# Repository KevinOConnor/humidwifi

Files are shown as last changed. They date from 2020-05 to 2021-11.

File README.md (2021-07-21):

This is an experimental pcb design for a battery powered wireless
humidity, temperature, and pressure sensor. It uses an esp32 wifi chip
along with a bme280 sensor.

This is an experiment. There is no support for this project.

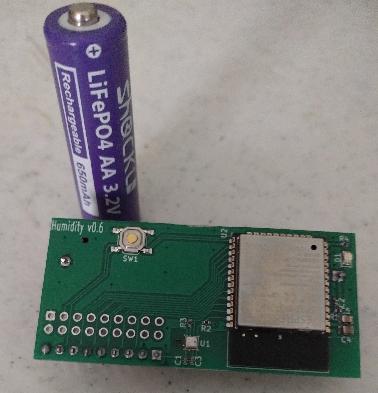
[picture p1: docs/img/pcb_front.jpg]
pcb_front


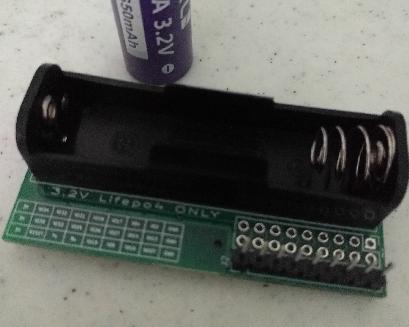
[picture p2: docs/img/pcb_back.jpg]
pcb_back


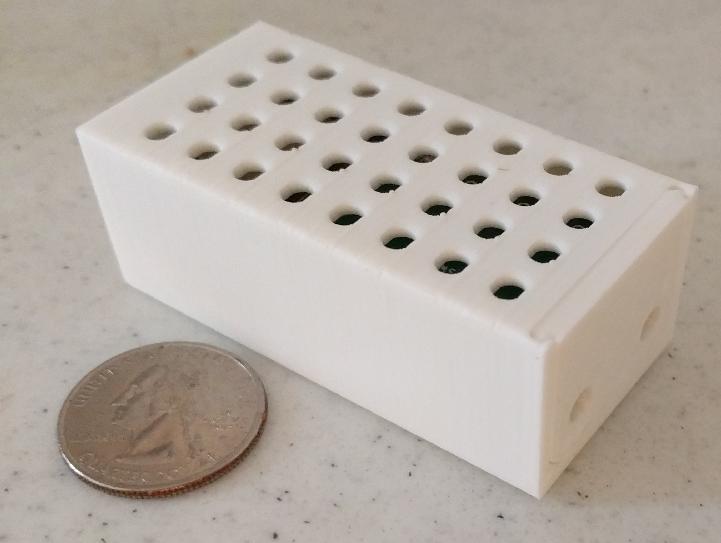
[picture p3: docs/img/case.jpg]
case


There is some information on the pcb design in the
[pcb document](docs/PCB.md).

There is some information on building the firmware in the
[firmware document](docs/Firmware.md).

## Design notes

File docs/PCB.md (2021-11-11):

The PCB design files can be found in the [pcb/](../pcb/) directory.
The boards were designed using [KiCad](https://kicad.org/) and
manufactured using [JLC PCB](https://jlcpcb.com/).

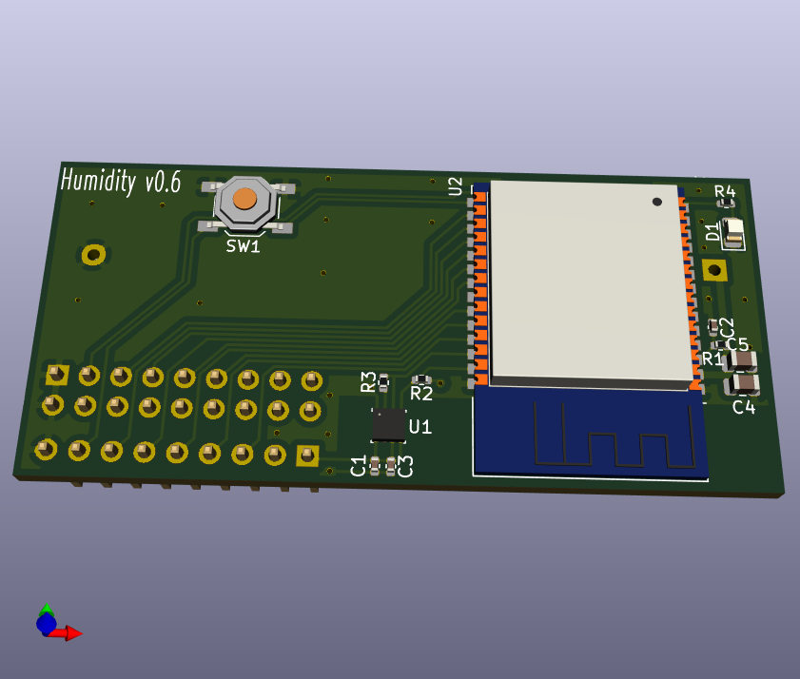
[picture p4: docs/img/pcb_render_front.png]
pcb_render_front


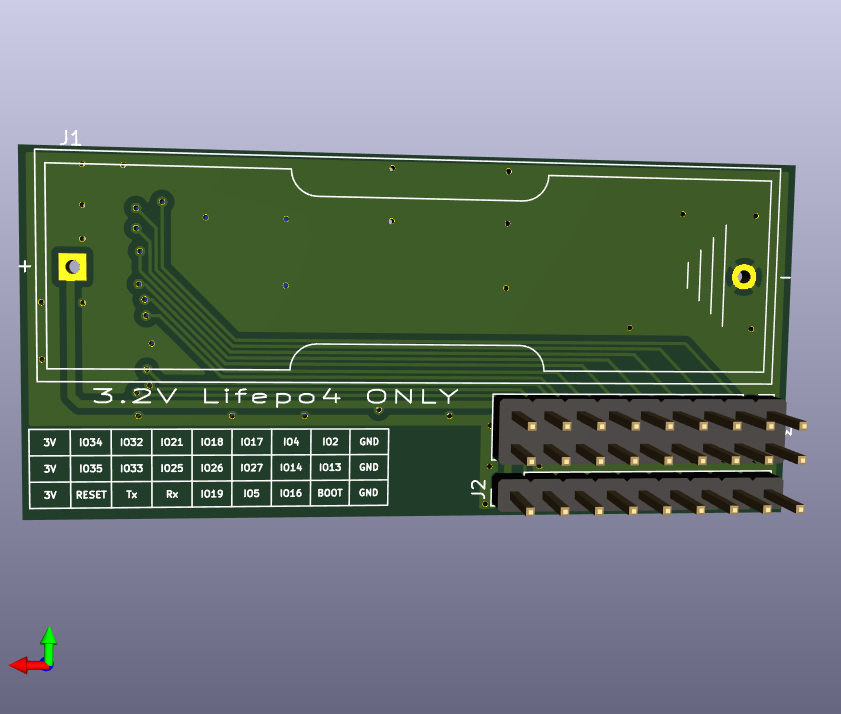
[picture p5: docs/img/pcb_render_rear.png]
pcb_render_rear


The board is designed to use a 3.2V LiFePO4 battery. The device will
not function properly with a 3.7V Lithium battery nor with a regular
alkaline AA battery - inserting an incorrect battery is likely to
permanently damage the board and it may result in a fire hazard.

Case
====

The design for a plastic case can be found in the [case/](../case/)
directory. It can be printed using a 3d-printer. The case was designed
using [OpenSCAD](https://www.openscad.org/).

case

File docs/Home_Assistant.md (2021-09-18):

To use these devices with Home Assistant, the easiest way is to seed Home Assistant manually
with MQTT Discovery commands about the device and the state topic.

To do this, run the `scripts/home_assistant_config.py` script, and provide the name of
the device.  This will print out the commands to run with `mosquitto_pub` to seed Home Assistant.

Once Home Assistant is seeded with the configuration, it typically does not need it again.  It will
pull the data from the `/data` topic as instructed moving forward.

Example
=======

```
python3 ./scripts/home_assistant_config.py --name humidwifi-living-room --host mqtt.local

> run:
> mosquitto_pub -t 'homeassistant/sensor/humidwifi-living-room/temp/config' -h mqtt.local -m '{"name": "Temperature", "device_class": "temperature", "unique_id": "humidwifi-living-room-name", "state_topic": "humidwifi-living-room/data", "unit_of_measurement": "\u00b0C", "value_template": "{{value_json.temperature}}", "device": {"manufacturer": "espressif", "identifiers": "humidwifi-living-room", "name": "humidwifi-living-room"}}' -r
> mosquitto_pub -t 'homeassistant/sensor/humidwifi-living-room/humidity/config' -h mqtt.local -m '{"name": "Humidity", "device_class": "humidity", "unique_id": "humidwifi-living-room-humidity", "state_topic": "humidwifi-living-room/data", "unit_of_measurement": "%", "value_template": "{{value_json.humidity}}", "device": {"manufacturer": "espressif", "identifiers": "humidwifi-living-room", "name": "humidwifi-living-room"}}' -r
> mosquitto_pub -t 'homeassistant/sensor/humidwifi-living-room/pressure/config' -h mqtt.local -m '{"name": "Pressure", "device_class": "pressure", "unique_id": "humidwifi-living-room-pressure", "state_topic": "humidwifi-living-room/data", "unit_of_measurement": "hPa", "value_template": "{{value_json.pressure}}", "device": {"manufacturer": "espressif", "identifiers": "humidwifi-living-room", "name": "humidwifi-living-room"}}' -r
> mosquitto_pub -t 'homeassistant/sensor/humidwifi-living-room/voltage/config' -h mqtt.local -m '{"name": "Voltage", "device_class": "voltage", "unique_id": "humidwifi-living-room-voltage", "state_topic": "humidwifi-living-room/data", "unit_of_measurement": "V", "value_template": "{{value_json.battery}}", "device": {"manufacturer": "espressif", "identifiers": "humidwifi-living-room", "name": "humidwifi-living-room"}}' -r

````

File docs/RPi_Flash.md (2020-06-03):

This document provides some hints on flashing the esp32 chip using a
Raspberry Pi's GPIO pins.

Wiring
======

The PCB's GPIO pins (from esp32 chip to board edge) are:
`GND, Tx, Rx, Boot, Reset, 3.3V`

Start by removing the battery and then use female to female jumper
cables to connect the PCB pins to the Raspberry Pi's GPIO
pins. Connect ground first and connect 3.3V last.

Important! Do not connect the 3.3V line while the battery is
installed.

Make these connections:
```
GND   -> RPi GND  (Pin 6)
Tx    -> RPi Rx   (Pin 10)
Rx    -> RPi Tx   (Pin 8)
Boot  -> RPi GND  (Pin 14)
Reset -> Not connected
3.3V  -> RPi 3.3V (Pin 1)
```

See https://pinout.xyz/ for a picture showing the Raspberry Pi GPIO
pins.

Software
========

The easiest way to build and install the software is to install and
compile the full
[esp-idf](https://docs.espressif.com/projects/esp-idf/en/v4.1-beta1/get-started/index.html)
environment on the Raspberry Pi and run `idf.py menuconfig ; idf.py
build ; idf.py -p /dev/ttyAMA0 flash`.

As an alternative, it is also possible to install just the idf
flashing tool and copy the binary components from a build on a desktop
computer. To do this, first install the esp32 flash tool:
```
virtualenv ~/esphome-env
~/esptool-env/bin/pip install esptool
```

Then copy the firmware files from a desktop to the Raspberry Pi with
something like:
```
cd /path/to/humidwifi/
rsync -av fw/build/partition_table/partition-table.bin fw/build/bootloader/bootloader.bin fw/build/humidwifi.bin pi@raspberrypi:~/
```

If one wishes to first erase the flash (which is not normally needed)
then one can run the following on the Raspberry Pi:
```
~/esptool-env/bin/esptool.py -p /dev/ttyAMA0 erase_flash
```
After this completes (it will take 30 seconds or so to erase the
chip), reset the PCB by carefully unplugging the 3.3V pin from the
PCB, wait 5 seconds, and then reconnect the 3.3V wire.

One can program the new flash with:
```
~/esptool-env/bin/esptool.py -p /dev/ttyAMA0 write_flash 0x8000 partition-table.bin 0x1000 bootloader.bin 0x10000 humidwifi.bin
```

Once the new firmware is written, carefully unplug the 3.3V wire
followed by the remaining wires. Insert the battery to start the new
firmware.

Important! Do not install the battery while the the 3.3V line is
connected.

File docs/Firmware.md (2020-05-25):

There is custom firmware available for this PCB design in the
[fw/](../fw/) directory. This document provides some overview
information for the firmware.

Building the firmware
=====================

The code uses the
[esp-idf](https://docs.espressif.com/projects/esp-idf/en/latest/esp32/index.html)
framework. To build the firmware run:

```
cd /path/to/humidwifi/
docker run --rm -v ./fw:/project -w /project -it espressif/idf:release-v4.1 idf.py menuconfig
docker run --rm -v ./fw:/project -w /project -it espressif/idf:release-v4.1 idf.py build
```

In the menuconfig step, be sure to enter the `Application settings for
'humidity wifi' project` and configure the appropriate MQTT and
network settings.

After configuring and building the software it will be necessary to
flash the software to the board. This can be done by running something
like `docker run --rm -v ./fw:/project -w /project -it
espressif/idf:release-v4.1 idf.py flash`, but it will require
configuring docker to have direct access to the device's serial port
(which is outside the scope of this document).

Overview and notes
==================

The software was designed to minimize battery usage during normal
operation. The goal is to keep the esp32 in "deep sleep" mode for the
vast majority of its lifetime. Sensor readings are taken periodically,
the results are stored to the esp32's "low power rtc memory", and then
the device reenters deep sleep mode. Periodically the device will also
turn on the radio, upload stored sensor readings, check for an
"over-the-air flash request", and then turn off the radio. Priority is
given to minimizing the amount of time that the wifi radio is enabled.
Minimizing the radio time greatly reduces the battery drain.

The software performs all uploads via an MQTT server. It should be
possible to configure the MQTT URI to use a username/password and/or
to use a TLS encrypted connection. The code does not currently have a
method to store TLS certificates however. The code does set the MQTT
"retain" flag, which may not be compatible with some "cloud" MQTT
servers. It should work with a local
[Mosquitto MQTT](https://mosquitto.org/) server.

Battery measurement
===================

The firmware uses an esp32 "trick" to measure the battery voltage. It
enables both the pullup and pulldown resistors of an unconnected ADC2
pin and then performs an ADC measurement. The pullup/pulldown
resistors form a "voltage divisor" which can be used to measure the
battery voltage. In theory, this "trick" would result in an ADC
reading that is half the battery voltage and therefore one would scale
this value by a factor of 2.0 to obtain the actual battery voltage.
However, the on-chip pullup/pulldown resistors may have slightly
different resistances.

The resistance difference is usually minor, but one can account for it
if they wish. While the device is powered and running, use a
multimeter to measure the actual voltage across the battery terminals.
Compare this voltage with the voltage reported by the software and
update the `Voltage scale` parameter in the "menuconfig" tool
accordingly.

Over-the-air flash
==================

It is possible to flash new versions of the software using an "over
the air" update. This is done by writing a URL to the `topic/ota_url`
MQTT topic (where `topic` is the topic prefix specified in
menuconfig). The URL should be an http (or https) link. For example:

```
mosquitto_pub -t "topic/ota_url" -m "http://myserver:8080/humidwifi.bin" -r
```

When the device next attempts to upload values, it will look for that
topic and then attempt to download the given firmware. One can launch
a temporary http server with something like:

```
cd /path/to/humidwifi/fw/build/
python -m SimpleHTTPServer 8080
```

It should be possible to use an https server, however the code does
not currently verify TLS certificates.

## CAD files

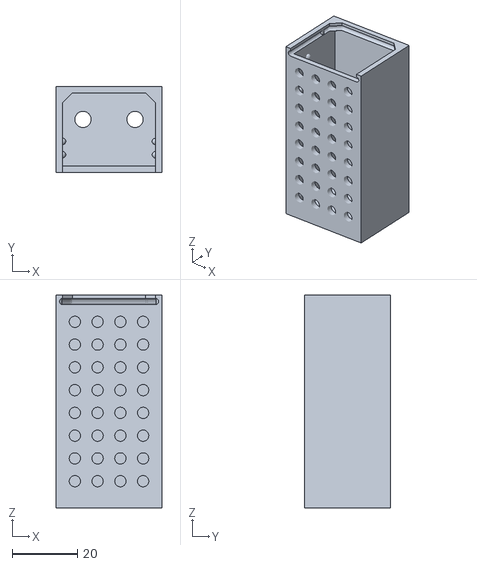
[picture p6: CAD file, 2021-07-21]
case/humcase.stl
32.5 x 26.5 x 65.5

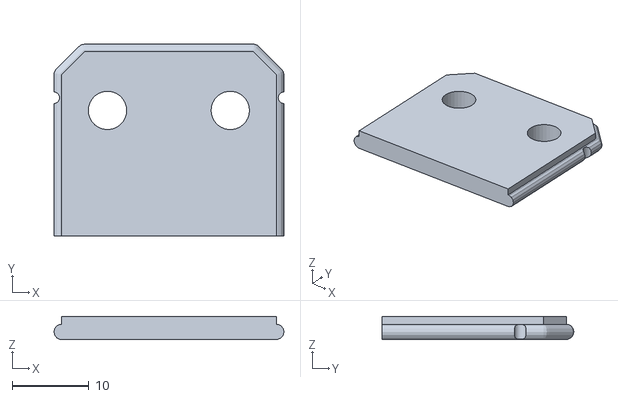
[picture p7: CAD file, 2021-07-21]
case/humlid.stl
30.0 x 25.0 x 3.00

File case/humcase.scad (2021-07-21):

// Case for storing humidity sensor
//
// Copyright (C) 2020-2021  Kevin O'Connor <kevin@koconnor.net>
//
// This file may be distributed under the terms of the GNU GPLv3 license.

// Generate STL using OpenSCAD:
//   openscad humcase.scad -o humcase.stl

pcb_width = 28;
pcb_thick = 1.6;
pcb_length = 60;
batt_thick = 18.5;
esp_thick = 3.5;
extra_thick = 0;
wall_width = 2;
guide_diamenter = 2;
lid_height = 3;
lid_diameter = 2;
air_hole_diameter = 3.5;
slack = 0.5;
CUT = 0.01;
$fs = 0.5;

module lid_frame(width, thick) {
    taper = 3;
    module raw_lid() {
        module rpoint(x1, y1) {
            translate([x1, y1, lid_diameter/2])
                sphere(d=lid_diameter);
        }
        hull() {
            rpoint(0, 0);
            rpoint(0, thick-taper);
            rpoint(taper, thick);
            rpoint(width-taper, thick);
            rpoint(width, thick-taper);
            rpoint(width, 0);
        }
        linear_extrude(height=lid_height) {
            polygon([[0,0], [0, thick-taper], [taper, thick],
                     [width-taper, thick], [width, thick-taper], [width, 0]]);
        }
    }
    module dimples() {
        dimple_diameter = 1.5;
        x_offset = lid_diameter/2;
        y_pos = thick - taper - 3;
        translate([-x_offset, y_pos, -CUT])
            cylinder(h=lid_height + 2*CUT, d=dimple_diameter, $fs=.1);
        translate([width + x_offset, y_pos, -CUT])
            cylinder(h=lid_height + 2*CUT, d=dimple_diameter, $fs=.1);
    }
    difference() {
        raw_lid();
        translate([-lid_diameter/2 - CUT, -lid_diameter, 0])
            cube([width + lid_diameter + 2*CUT, lid_diameter,
                  lid_height + 2*CUT]);
        dimples();
    }
}

module battery_air_hole(x, y) {
    batt_air_hole_diameter = 5;
    translate([x, y, -CUT])
        cylinder(h=lid_height + 2*CUT, d=batt_air_hole_diameter);
}

batt_hole_y = extra_thick + esp_thick + pcb_thick + wall_width + batt_thick/2;

module lid() {
    difference() {
        lid_frame(pcb_width, batt_thick + esp_thick + extra_thick + wall_width);
        battery_air_hole(6, batt_hole_y);
        battery_air_hole(pcb_width-6, batt_hole_y);
    }
}

module case() {
    width = pcb_width + slack;
    thick = batt_thick + esp_thick + extra_thick + slack;
    height = pcb_length + lid_height + slack;
    two_wall = 2 * wall_width;
    module box() {
        difference() {
            cube([width + two_wall, thick + two_wall, height + wall_width]);
            translate([wall_width, wall_width, wall_width])
                cube([width, thick, height - lid_height + 2*CUT]);
            translate([wall_width, -CUT, wall_width + pcb_length + slack + CUT])
                lid_frame(width, thick + wall_width);
        }
    }
    module pcb_guide(z) {
        top_space = esp_thick + wall_width + extra_thick;
        guide_space = pcb_thick + guide_diamenter + slack;
        front_place = wall_width;
        rear_place = wall_width + width;
        translate([front_place, top_space, z+wall_width])
            sphere(d=guide_diamenter);
        translate([front_place, top_space + guide_space, z+wall_width])
            sphere(d=guide_diamenter);
        translate([rear_place, top_space, z+wall_width])
            sphere(d=guide_diamenter);
        translate([rear_place, top_space + guide_space, z+wall_width])
            sphere(d=guide_diamenter);
    }
    module main_box() {
        box();
        pcb_guide(4);
        pcb_guide(15);
        pcb_guide(pcb_length-15);
        pcb_guide(pcb_length-4);
    }
    module air_holes(xpos_list, zpos_list) {
        module air_hole(x, z) {
            translate([x, -CUT, z])
                rotate([-90, 0, 0])
                    cylinder(h=wall_width + 2*CUT, d=air_hole_diameter);
        }
        center_x = (width + two_wall) / 2;
        center_z = (height + wall_width) / 2;
        gap = 2 * air_hole_diameter;
        for (xpos=xpos_list) {
            x = center_x + gap * xpos;
            for (zpos=zpos_list) {
                z = center_z + gap * zpos;
                air_hole(x, z);
            }
        }
    }
    difference() {
        main_box();
        air_xlist = [-1.5, -0.5, .5, 1.5];
        air_zlist = [-3.5, -2.5, -1.5, -0.5, .5, 1.5, 2.5, 3.5];
        air_holes(air_xlist, air_zlist);
        battery_air_hole(wall_width + slack / 2 + 6, batt_hole_y);
        battery_air_hole(width + wall_width - slack / 2 - 6, batt_hole_y);
    }
}

//
// Object selection
//

case();
//lid();

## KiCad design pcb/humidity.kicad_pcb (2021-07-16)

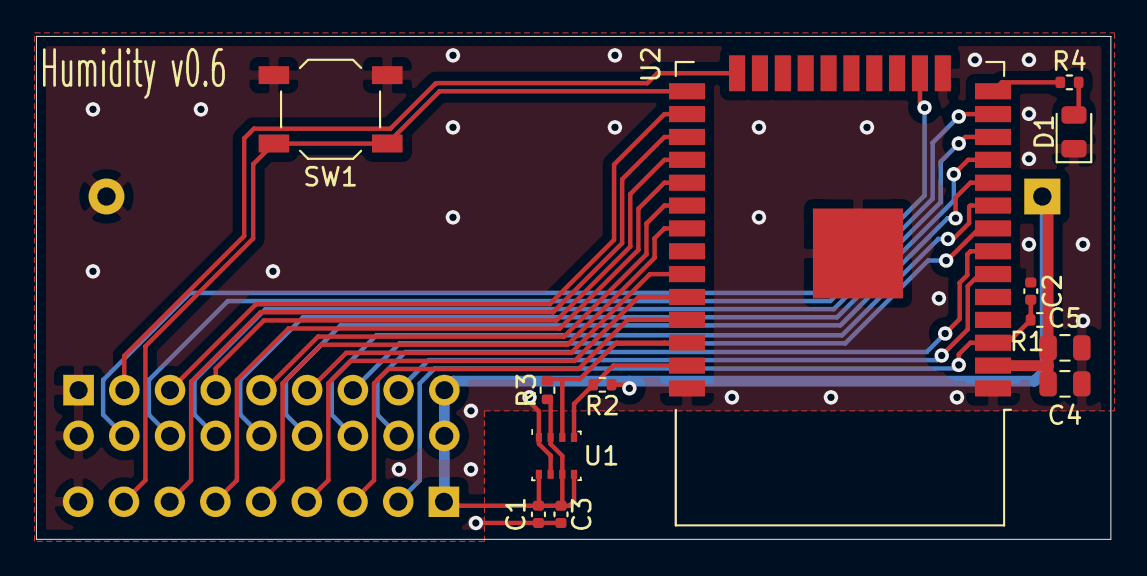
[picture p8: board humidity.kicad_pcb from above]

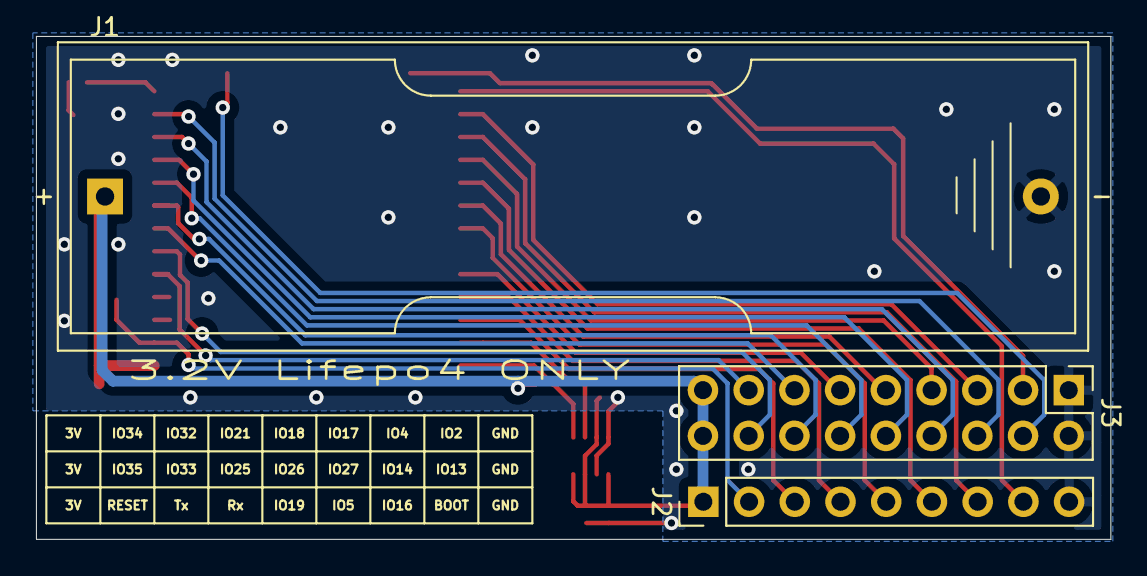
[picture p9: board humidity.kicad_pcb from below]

Board: 2 copper layers, 59.7 x 27.9 mm, 16 parts (3 on the bottom side), 27 nets.

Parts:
C1, C2, C3: 100nF; C_0402_1005Metric
C4: 10uF; C_0805_2012Metric
C5: 100nF; C_0805_2012Metric
D1: Red LED; LED_0805_2012Metric
J1: Battery Holder; BatteryHolder_Keystone_2460_1xAA
J2: Conn_01x09; PinHeader_1x09_P2.54mm_Vertical
J3: Conn_02x09_Odd_Even; PinHeader_2x09_P2.54mm_Vertical
R1: 10K; R_0402_1005Metric
R2, R3: 4K7; R_0402_1005Metric
R4: 0K1; R_0402_1005Metric
SW1: SW_Push; SW_SPST_TL3342
U1: BME280; Bosch_LGA-8_2.5x2.5mm_P0.65mm_ClockwisePinNumbering
U2: ESP32-WROOM-32

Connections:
+BATT: C1.1, C3.1, C4.1, C5.1, J1.1, J2.1, J3.17, J3.18, R1.1, R2.1, R3.1, U1.2, U1.5, U1.6, U1.8, U2.2
BOOT: J2.8, SW1.1, U2.25
GND: C1.2, C2.2, C3.2, C4.2, C5.2, D1.1, J1.2, J2.9, J3.1, J3.2, SW1.2, U1.1, U1.7, U2.1, U2.15, U2.38, U2.39
IO2: J3.3, U2.24
IO4: J3.5, U2.26
IO5: J2.6, U2.29
IO13: J3.4, U2.16
IO14: J3.6, U2.13
IO16: J2.7, U2.27
IO17: J3.7, U2.28
IO18: J3.9, U2.30
IO19: J2.5, U2.31
IO21: J3.11, U2.33
IO25: J3.12, U2.10
IO26: J3.10, U2.11
IO27: J3.8, U2.12
IO32: J3.13, U2.8
IO33: J3.14, U2.9
IO34: J3.15, U2.6
IO35: J3.16, U2.7
LED: R4.1, U2.14
unnamed: D1.2, R4.2
RESET: C2.1, J2.2, R1.2, U2.3
RXD: J2.4, U2.34
SCL: R2.2, U1.4, U2.37
SDA: R3.2, U1.3, U2.36
TXD: J2.3, U2.35

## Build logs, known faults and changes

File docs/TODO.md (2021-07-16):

Possible future enhancements.

There is no support for this device. These enhancements may or may not
be implemented.

PCB
===

* Possibly route GPIO15 to GND to suppress rom boot debug messages.
  (Currently GPIO15 is used for battery measurements.)

Firmware
========

* Store user settings in a config file stored in flash, instead of
  configuring via "menuconfig". This would make it easier to configure
  and distribute the device (as a single binary image could be used
  for many devices).

* Support a "configuration mode" where the device starts in AP mode
  and allows a user to configure settings via an http server.

* The esp-idf mqtt implementation is not optimized for bulk uploads.
  It is thought that a custom mqtt implementation could notably reduce
  measurement upload time, which could extend battery charge.

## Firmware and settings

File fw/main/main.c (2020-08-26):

// Application start and main loop
//
// Copyright (C) 2020  Kevin O'Connor <kevin@koconnor.net>
//
// This file may be distributed under the terms of the GNU GPLv3 license.

#include <stdio.h> // snprintf
#include <esp_attr.h> // RTC_DATA_ATTR
#include <esp_log.h> // ESP_LOGI
#include "battery.h" // battery_sense
#include "bme280.h" // bme280_sense
#include "datalog.h" // datalog_init
#include "deepsleep.h" // deepsleep_init
#include "mqtt.h" // mqtt_start
#include "network.h" // network_connect
#include "sdkconfig.h" // CONFIG_UPLOAD_INTERVAL

static const char *TAG = "MQTT_TCP";


/****************************************************************
 * Wake and sleep time reports
 ****************************************************************/

struct appwake_s {
    uint64_t waketime, sleeptime;
};

static int
appwake_format(void *data, char *buf, int size)
{
    struct appwake_s *aw = data;
    const char *latest = "";
    if (aw->waketime == deepsleep_get_wake_time())
        latest = ",\"latest\":1";
    if (!aw->sleeptime)
        return snprintf(buf, size, "\"boot_time\":%llu%s"
                        , aw->waketime, latest);
    return snprintf(buf, size, "\"wake_time\":%llu,\"last_sleep_time\":%llu%s"
                    , aw->waketime, aw->sleeptime, latest);
}

static const struct datalog_type_s appwake_info = {
    .length = sizeof(struct appwake_s),
    .format = appwake_format,
};

static void
waketime_sense(void)
{
    struct appwake_s aw = {
        .waketime = deepsleep_get_wake_time(),
        .sleeptime = deepsleep_get_sleep_time(),
    };
    datalog_append(&appwake_info, &aw);
}


/****************************************************************
 * Startup
 ****************************************************************/

// Setup debug levels
static void
debug_init(void)
{
    ESP_LOGW(TAG, "[APP] Startup..");
}

static RTC_DATA_ATTR uint64_t next_network_time;

// Main esp32 code start
void
app_main(void)
{
    deepsleep_init();
    debug_init();
    datalog_init();

    waketime_sense();
    battery_sense();
    bme280_sense();
    datalog_finalize();

    // Check if network upload should be attempted
    if (deepsleep_get_wake_time() >= next_network_time) {
        uint64_t upload_interval = CONFIG_UPLOAD_INTERVAL * 1000000ULL;
        next_network_time = deepsleep_get_wake_time() + upload_interval;

        int ret = network_start();
        if (ret)
            goto done;
        mqtt_start();

        network_disconnect();
    }

done:
    deepsleep_start_sleep();
}

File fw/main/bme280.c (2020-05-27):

// BME280 humidity sensor support
//
// Copyright (C) 2020  Kevin O'Connor <kevin@koconnor.net>
//
// This file may be distributed under the terms of the GNU GPLv3 license.

#include <driver/i2c.h> // i2c_param_config
#include <esp_attr.h> // RTC_DATA_ATTR
#include <esp_log.h> // ESP_LOGW
#include "bme280.h" // bme280_sense
#include "datalog.h" // datalog_append
#include "deepsleep.h" // deepsleep_is_wake_from_sleep
#include "sdkconfig.h" // CONFIG_BME280_SDA_GPIO

#define I2C_FREQUENCY 100000

static const char *TAG = "BME280";


/****************************************************************
 * I2C helpers
 ****************************************************************/

static int
i2c_init(void)
{
    int ret = i2c_driver_install(I2C_NUM_0, I2C_MODE_MASTER, 0, 0, 0);
    if (ret)
        return ret;

    i2c_config_t conf = {
        .mode = I2C_MODE_MASTER,
        .sda_io_num = CONFIG_BME280_SDA_GPIO,
        .sda_pullup_en = GPIO_PULLUP_ENABLE,
        .scl_io_num = CONFIG_BME280_SCL_GPIO,
        .scl_pullup_en = GPIO_PULLUP_ENABLE,
        .master.clk_speed = I2C_FREQUENCY,
    };
    return i2c_param_config(I2C_NUM_0, &conf);
}

static int
i2c_write(uint8_t reg, uint8_t data)
{
    int i2c_addr = CONFIG_BME280_I2C_ADDR;
    i2c_cmd_handle_t cmd = i2c_cmd_link_create();
    i2c_master_start(cmd);
    i2c_master_write_byte(cmd, i2c_addr << 1 | I2C_MASTER_WRITE, 1);
    i2c_master_write_byte(cmd, reg, 1);
    i2c_master_write_byte(cmd, data, 1);
    i2c_master_stop(cmd);
    esp_err_t ret = i2c_master_cmd_begin(I2C_NUM_0, cmd, 50 / portTICK_RATE_MS);
    i2c_cmd_link_delete(cmd);
    return ret;
}

static int
i2c_read(uint8_t reg, uint8_t *data, int len)
{
    int i2c_addr = CONFIG_BME280_I2C_ADDR;
    i2c_cmd_handle_t cmd = i2c_cmd_link_create();
    i2c_master_start(cmd);
    i2c_master_write_byte(cmd, i2c_addr << 1 | I2C_MASTER_WRITE, 1);
    i2c_master_write_byte(cmd, reg, 1);
    i2c_master_start(cmd);
    i2c_master_write_byte(cmd, i2c_addr << 1 | I2C_MASTER_READ, 1);
    if (len > 1)
        i2c_master_read(cmd, data, len - 1, 0);
    i2c_master_read_byte(cmd, &data[len - 1], 1);
    i2c_master_stop(cmd);
    esp_err_t ret = i2c_master_cmd_begin(I2C_NUM_0, cmd, 50 / portTICK_RATE_MS);
    i2c_cmd_link_delete(cmd);
    return ret;
}


/****************************************************************
 * BME280 calibration and config
 ****************************************************************/

struct bme280_calibration_s {
    uint16_t dig_T1;
    int16_t dig_T2;
    int16_t dig_T3;
    uint16_t dig_P1;
    int16_t dig_P2;
    int16_t dig_P3;
    int16_t dig_P4;
    int16_t dig_P5;
    int16_t dig_P6;
    int16_t dig_P7;
    int16_t dig_P8;
    int16_t dig_P9;
    uint8_t dig_H1;
    uint8_t dig_H3;
    int16_t dig_H2;
    int16_t dig_H4;
    int16_t dig_H5;
    int8_t dig_H6;
};
static RTC_DATA_ATTR struct bme280_calibration_s calib;

static inline uint16_t load_short(uint8_t *p) {
    return (p[1] << 8) | p[0];
}

static int
bme280_configure(void)
{
    // Read calibration data
    uint8_t data[0x9f - 0x88 + 1];
    int ret = i2c_read(0x88, data, sizeof(data));
    if (ret)
        goto fail;
    calib.dig_T1 = load_short(&data[0]);
    calib.dig_T2 = load_short(&data[2]);
    calib.dig_T3 = load_short(&data[4]);
    calib.dig_P1 = load_short(&data[6]);
    calib.dig_P2 = load_short(&data[8]);
    calib.dig_P3 = load_short(&data[10]);
    calib.dig_P4 = load_short(&data[12]);
    calib.dig_P5 = load_short(&data[14]);
    calib.dig_P6 = load_short(&data[16]);
    calib.dig_P7 = load_short(&data[18]);
    calib.dig_P8 = load_short(&data[20]);
    calib.dig_P9 = load_short(&data[22]);
    ret = i2c_read(0xA1, &calib.dig_H1, 1);
    if (ret)
        goto fail;
    ret = i2c_read(0xE1, data, 0xe7 - 0xe1 + 1);
    if (ret)
        goto fail;
    calib.dig_H2 = load_short(&data[0]);
    calib.dig_H3 = data[2];
    calib.dig_H4 = (data[3] << 4) | (data[4] & 0x0f);
    calib.dig_H5 = (data[4] >> 4) | (data[5] << 4);
    calib.dig_H6 = data[6];

    // Setup humidity control
    uint8_t ctrl_hum = 0x1;
    ret = i2c_write(0xf2, ctrl_hum);
    if (ret)
        goto fail;

    return 0;

fail:
    ESP_LOGW(TAG, "bme280_configure error %d", ret);
    return ret;
}

// Calculate temperature (formula from bme280 spec)
static int32_t
bme280_calc_t_fine(uint8_t *data)
{
    int32_t adc_T = (data[3] << 12) | (data[4] << 4) | (data[5] >> 4);
    int32_t dig_T1 = calib.dig_T1, dig_T2 = calib.dig_T2, dig_T3 = calib.dig_T3;

    int32_t var1 = (((adc_T >> 3) - (dig_T1 << 1)) * dig_T2) >> 11;
    int32_t var2 = (((((adc_T >> 4) - dig_T1) * ((adc_T >> 4) - dig_T1)) >> 12)
                    * dig_T3) >> 14;
    return var1 + var2;
}

// Convert temperature to float
static float
bme280_calc_temperature(int32_t t_fine)
{
    return t_fine / 5120.0f;
}

// Calculate pressure (formula from bme280 spec)
static float
bme280_calc_pressure(int32_t t_fine, uint8_t *data)
{
    int32_t adc_P = (data[0] << 12) | (data[1] << 4) | (data[2] >> 4);
    int64_t dig_P1 = calib.dig_P1, dig_P2 = calib.dig_P2, dig_P3 = calib.dig_P3;
    int64_t dig_P4 = calib.dig_P4, dig_P5 = calib.dig_P5, dig_P6 = calib.dig_P6;
    int64_t dig_P7 = calib.dig_P7, dig_P8 = calib.dig_P8, dig_P9 = calib.dig_P9;

    int64_t var1 = (int64_t)t_fine - 128000;
    int64_t var2 = var1 * var1 * dig_P6;
    var2 = var2 + ((var1 * dig_P5) << 17);
    var2 = var2 + (dig_P4 << 35);
    var1 = ((var1 * var1 * dig_P3) >> 8) + ((var1 * dig_P2) << 12);
    var1 = (((1LL << 47) + var1) * dig_P1) >> 33;
    if (!var1)
        return 0.;
    int64_t p = 1048576 - adc_P;
    p = (((p << 31) - var2) * 3125) / var1;
    var1 = (dig_P9 * (p >> 13) * (p >> 13)) >> 25;
    var2 = (dig_P8 * p) >> 19;
    p = ((p + var1 + var2) >> 8) + (dig_P7 << 4);

    return (uint32_t)p / 25600.0f;
}

// Calculate humidity (formula from bme280 spec)
static float
bme280_calc_humidity(int32_t t_fine, uint8_t *data)
{
    int32_t adc_H = (data[6] << 8) | data[7];
    int32_t dig_H1 = calib.dig_H1, dig_H2 = calib.dig_H2, dig_H3 = calib.dig_H3;
    int32_t dig_H4 = calib.dig_H4, dig_H5 = calib.dig_H5, dig_H6 = calib.dig_H6;

    int32_t v_x1_u32r = t_fine - 76800;
    v_x1_u32r =
        ((((adc_H << 14) - (dig_H4 << 20) - (dig_H5 * v_x1_u32r)) + 16384) >> 15)
        * (((((((v_x1_u32r * dig_H6) >> 10)
               * (((v_x1_u32r * dig_H3) >> 11) + 32768)) >> 10) + 2097152)
            * dig_H2 + 8192) >> 14);
    v_x1_u32r = v_x1_u32r - (((((v_x1_u32r >> 15)
                                * (v_x1_u32r >> 15)) >> 7) * dig_H1) >> 4);
    v_x1_u32r = v_x1_u32r < 0 ? 0 : v_x1_u32r;
    v_x1_u32r = v_x1_u32r > 419430400 ? 419430400 : v_x1_u32r;

    return (v_x1_u32r >> 12) / 1024.0f;
}


/****************************************************************
 * BME280 datalog entry
 ****************************************************************/

struct bme280_s {
    float temperature, pressure, humidity;
};
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

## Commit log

2019-12-27 Iniital commit
    [humidity.kicad_pcb, humidity.sch]
2020-01-01 Updates for Lifepo4 battery
    Use a 3.2V lifepo4 battery. This eliminates the need for a regulator.
    Remove the battery sensing circuit - the esp32 ADC should be able to
    sense VDD33 directly.
    Add an N-MOSFET on BATT- to protect against battery reverse polarity.
    Use 0805 LED size. Adjust LED resistor to 100ohm.
    Use wider traces for VBATT lines.
    [humidity.kicad_pcb, humidity.sch]
2020-01-02 Updates for JLCPCB
    Add LCSC part numbers (in case using JLCPCB to assemble).
    Use 0805 for the caps (as they're cheaper on JLCPCB).
    Add version information to silk screen. Add a warning about
    appropriate battery to the silk screen.
    [humidity.kicad_pcb, humidity.sch]
2020-01-02 Rework bme280 wire routing
    Simplify the wiring to the bme280. Improve the cap locations near the
    bme280.
    Add a 10K resistor to MOSFET gate (for ESD).
    Fix location of silk screen text.
    [humidity.kicad_pcb, humidity.sch]
2020-01-02 Further updates to n-mosfet
    Use AO3416 n-mosfet (which has ESD).
    Move n-mosfet to corner. Relocate the n-mosfet away from the edge and
    to reduce crowding.
    Minor wire routing improvements.
    [humidity.kicad_pcb, humidity.sch]
2020-02-23 case: Initial 3d printed case for sensor pcb
    [humcase.scad, humcase.stl, humlid.stl]
2020-05-16 pcb: Rename humidity/ directory to pcb/ directory
    [humidity.kicad_pcb, humidity.sch]
2020-05-16 fw: Add initial support for esp-idf based firmware
    [partitions.csv]
2020-05-16 docs: Add "battery measurement" note to Firmware.md
2020-05-17 bme280: Avoid truncation of t_fine in conversion of temperature
    [bme280.c]
2020-05-17 battery: Use calibrated adc to voltage conversion
2020-05-25 deepsleep: Do not call rtc_gpio_isolate()
    Calling rtc_gpio_isolate() is actually increasing the power
    consumption in deepsleep mode.
2020-05-25 battery: Use simple scale/offset calculation
    Don't use the esp_adc_cal component and instead use configurable scale
    and offset settings to calibrate battery measurements.
2020-05-27 bme280: Pass full data array to bme280 calibration functions
2020-05-28 humcase: Updates to 3d printed case
    Add additional pcb guide protrusions. Add battery vent holes.
    [humcase.scad, humcase.stl, humlid.stl]
2020-06-03 docs: Fix pin assignment typo in RPi_Flash.md
2020-06-28 graph_data: Allow filtering data by a date range
2021-07-16 pcb: Update pcb with new routing (pcb v0.6)
    Move esp32 chip to side of board to allow more space for other
    components.
    Move bme280 chip away from battery and do not extend the ground plane
    under it. This is intended to improve thermal isolation of the bme280
    chip.
    Route most unused micro-controller pins to 2.54mm pins that are
    externally accessible.
    Add a surface mounted button component to the board.
    Remove reverse battery diode. The physical battery holder should
    prevent the battery from being inserted in an incorrect orientation.
    Note PCB revision on silkscreen as "v0.6".
    [humidity.kicad_pcb, humidity.sch]
2021-07-16 docs: Add PCB rendering of v0.6 pcb
2021-07-16 Kconfig: Change defaults for v0.6 pcb
    The latest PCB uses different pins for i2c and battery level checking.
2021-07-16 docs: Update TODO document
    Update the todo document with changes since v0.6 pcb design.
2021-07-16 README: Add pictures of assembled board
2021-07-18 docs: Fix typo in PCB.md
2021-07-21 case: Updates to case
    Increase size of lid "dimple" to improve lid locking.
    Slightly reduce y dimensions to reduce overall case size.
    Align air holes and decrease their size.
    Minor syntax cleanups.
    [humcase.scad, humcase.stl, humlid.stl]
2021-07-21 docs: Add a picture of the 3d printed case
2021-11-11 docs: Update to use https://kicad.org/
2022-02-09 calculate: Add helper script to calculate a battery scale
